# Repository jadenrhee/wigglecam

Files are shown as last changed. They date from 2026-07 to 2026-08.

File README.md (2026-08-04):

# WiggleCam

A four-lens camera where all four lenses fire at the same moment. The
four views are combined into a looping GIF that reads as 3-D, the same
effect as the Nishika N8000 film camera. A touchscreen handles the
preview and filter selection, and every shot ends with a QR code that
opens the GIF on any phone over the camera's own hotspot.

Design and firmware are done. Parts aren't ordered yet, so the images
here are renders.

<p align="center">
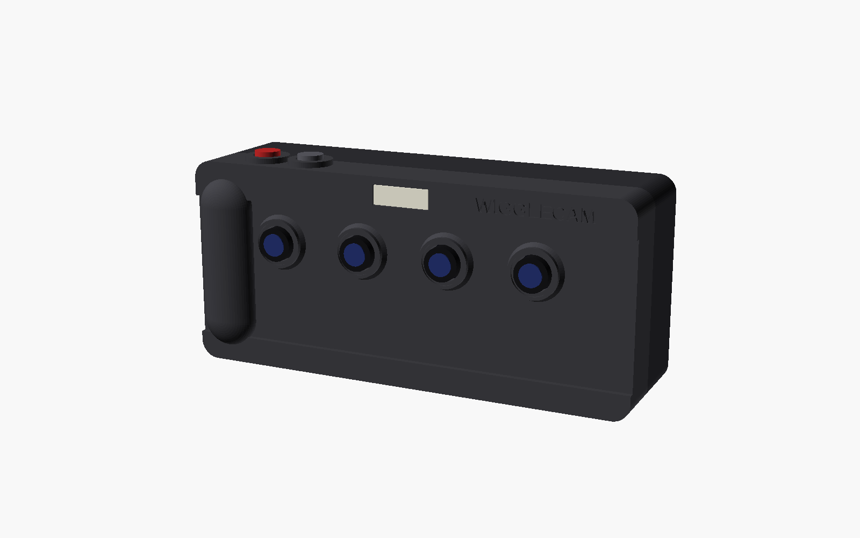
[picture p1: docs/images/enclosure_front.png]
Enclosure, front: four bezeled lenses, grip, top-plate shutter and filter buttons
  
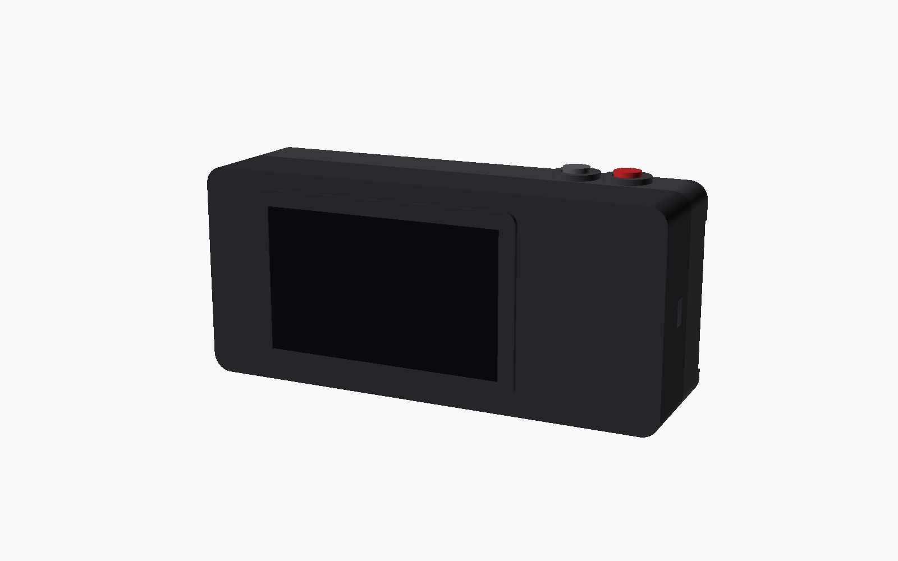
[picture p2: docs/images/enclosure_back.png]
Enclosure, back: 4.3 inch touchscreen
  
</p>

## How it works

Four 16 MP camera modules sit 40 mm apart behind the front plate. An
Arducam Camarray HAT drives all four from one clock and merges them into
a single 2x2 frame over one CSI cable. Sharing a frame puts each view at
roughly 4 MP, which is the tradeoff for hardware sync.

That shared clock is the reason for the HAT. Cameras triggered in
software drift by milliseconds, so a moving subject lands in a different
position in each frame and jumps between them instead of shifting
smoothly.

The firmware splits the frame and aligns the four views on the subject
using phase correlation on a center crop. It then applies the selected
filter and writes a bounce-looped GIF.

System wiring diagram

## Controller board

Linux is not a real-time OS, so the Pi can't be relied on to hit an
exact moment, and the jitter shows up as a flash firing outside the
exposure.
[wigglecam-controller](https://github.com/jadenrhee/wigglecam-controller)
handles the timing-critical work.

An RP2040 drives the flash at constant current and pulses the Pi the
instant the LEDs reach full current. It also debounces the shutter,
decodes the EC11 encoder, and monitors battery voltage and current
through an INA219. The Pi drives it over I2C at 0x17. The capture pulse
and an event flag come back on separate GPIO lines.

76 x 50 mm, 4 layers, DRC clean against JLCPCB's published 4-layer
rules, plus 24 checks measured off the finished layout. Not fabricated
yet either.

<p align="center">
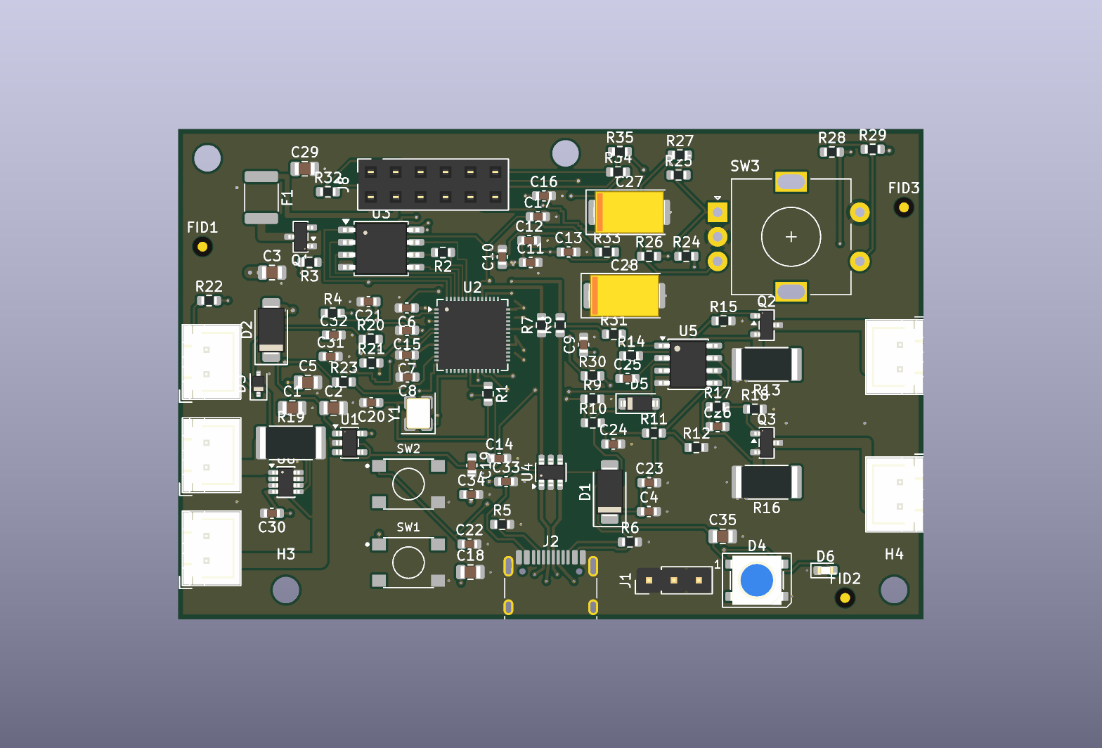
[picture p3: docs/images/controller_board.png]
Controller board, rendered top view
  
  PCB routing: front copper red, back copper blue
</p>

## Repo layout

| Path | Contents |
|---|---|
| [hardware/BOM.md](hardware/BOM.md) | full parts list, about $550 |
| [hardware/wiring.md](hardware/wiring.md) | connections, GPIO map, assembly order |
| [hardware/power-budget.md](hardware/power-budget.md) | load table and the math behind the 4.5 hour runtime |
| [hardware/safety-checklist.md](hardware/safety-checklist.md) | lithium and thermal rules. The cells are unprotected by design, so the BMS and these checks carry the safety case |
| [firmware/](firmware/) | Python app: capture, filters, alignment, GIF export, share server, UI |
| [enclosure/](enclosure/) | parametric OpenSCAD body and printing guide |
| [docs/architecture.md](docs/architecture.md) | reasoning behind each design decision |

## Running it (on the Pi)

```bash
sudo apt install -y python3-picamera2 python3-pyqt5 python3-opencv
python3 -m venv --system-site-packages .venv && source .venv/bin/activate
pip install -r firmware/requirements.txt
echo 'dtoverlay=imx519,cam0' | sudo tee -a /boot/firmware/config.txt && sudo reboot
# after reboot:
nmcli device wifi hotspot ssid WiggleCam password <choose-one>
cd firmware && python3 -m wigglecam.app
```

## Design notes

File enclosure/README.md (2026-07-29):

# Enclosure

The body is parametric OpenSCAD, all in
[wigglecam_body.scad](wigglecam_body.scad). It's styled like a wide
compact camera: raised top and bottom plates, bezeled lens rings, a
hand grip on the photographer's right, a shutter button on the top
plate, a flash window, and a raised screen bezel on the back.

Opened in [OpenSCAD](https://openscad.org) (free), pressing F5 renders the
default `PART = "assembly"`: the closed camera standing upright, with dummy
lenses/screen/button for a quick layout sanity-check. Setting `PART` to
`"front"` or `"back"` and pressing F6 renders a shell for export via
**File → Export → STL**.

The `scr_*`, `cam_*`, and `pi_*` variables hold the dimensions of the
actual delivered screen, camera modules, and Pi/UPS stack, measured with
calipers before any print. Vendor drawings drift between hardware
revisions, and a 1 mm error in the screen cutout ruins a 10-hour print.

## Printing without owning a printer

- **Public library or school makerspace.** Many offer free or at-cost
  prints. The 205 × 92 mm body fits a 220 × 220 mm bed straight-on. No
  rotation squeezes it onto a 200 × 200 mm bed (unrotated 205 mm is
  already the tightest bounding box), so for smaller beds reduce
  `body_w` or use a service with a larger bed.
- **[Craftcloud](https://craftcloud3d.com)** is a comparison marketplace
  for print services; upload the STL and pick PETG.
- **[JLC3DP](https://jlc3dp.com)** and **PCBWay** are cheap, good quality,
  and ship in about a week.

Recommended settings: **PETG** (more heat-tolerant than PLA, and the Pi 5
runs warm), 0.2 mm layers, 4 perimeters, 25 % infill.

**Orientation:** print both shells open-side down (cosmetic face up)
with supports on. The raised lens bezels, grip, and plates mean the
shells don't sit flat face-down anymore, and this way the support
marks end up inside the shell where nobody sees them.

## Assembly hardware

- 6x M3 heat-set brass inserts + M3x10 screws (join the shells)
- 16x M2x6 self-tapping screws (camera modules)
- 4x M2.5x16 standoff screws (Pi 5 + X1202 stack)
- 4x M3x8 screws (screen)
- 1x 1/4-20 hex nut, epoxied into the bottom pocket (tripod mount)
- a scrap of white PETG or frosted acrylic behind the flash window as
  a diffuser

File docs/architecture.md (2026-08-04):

# Architecture

I started from what a wigglegram actually needs and let each
requirement pick the hardware. This doc walks through that reasoning,
then covers the electronics, the data flow, and what I'd still like to
fix.

**1. Four views of the same instant.** If the four exposures are even a
few ms apart, anything moving (people, hair, leaves) ghosts between
frames and the 3-D illusion collapses. Software-triggering four
independent cameras (e.g. four ESP32-CAMs or four Pi cams on a mux that
*switches* between them) cannot achieve this. The Arducam Camarray HAT
clocks all four IMX519 sensors from one source and merges them into a
single 2×2-stitched frame. Because the sensors share that clock, the
exposures are simultaneous, and the Pi sees just one ordinary camera on
one CSI port.

**2. Parallax baseline.** The 3-D effect comes from the lenses being
horizontally offset. The enclosure spaces the four modules 40 mm apart
(120 mm outer baseline), close to the Nishika N8000 film camera that
inspired it. Frames are auto-aligned on the subject in software
(`wiggle.py`, phase correlation on a center crop) so the subject holds
still and the background does the wiggling.

**3. Handheld power.** The Pi 5 demands 5 V/5 A, beyond what generic power
banks and boost boards provide. The Geekworm X1202 (4×18650, BMS, 5.1 V/5 A) is
purpose-built for it and mounts under the Pi, keeping the top-side
camera/display connectors free.

**4. Instant sharing.** AirDrop is Apple-proprietary (AWDL) and not
implementable on a Pi. Instead the camera runs its own Wi-Fi hotspot
and a small Flask gallery (`share.py`); after each shot the touchscreen
shows a QR code that opens the GIF in any phone browser, iPhone or
Android, with no app to install.

## Data flow

```
4x IMX519 ─(hw sync)─▶ Camarray HAT ─CSI─▶ Picamera2
                                            ├── lores stream ─▶ Qt live preview (touch UI)
                                            └── still capture (4656x3496, flash bracketed)
                                                  └▶ split 2x2 ─▶ filter ─▶ align ─▶
                                                      ├▶ 4x JPEG stills
                                                      └▶ bounce GIF ─▶ Flask gallery ─▶ QR ─▶ phone
```

## Firmware layout

| Module | What it does |
|---|---|
| `config.py` | every tunable in one place |
| `camera.py` | Picamera2 setup, stitched capture, 2x2 split |
| `flash.py` | flash pulse control (v1 GPIO gate today; v2 I2C client planned) |
| `filters.py` | the filter looks (B&W, sepia, vivid, film), all pure functions |
| `wiggle.py` | subject alignment, bounce sequencing, GIF/JPEG export |
| `share.py` | hotspot gallery server + QR generation |
| `app.py` | Qt touch UI, buttons, capture orchestration |

## Known limitations / future work

- Quad synchronized mode caps each view at 2328×1748 (~4 MP). That's the
  price of single-cable hardware sync. It's enough for GIFs.
- GIF export ~2-4 s on the Pi 5; an MP4 export path would be smaller
  files and faster.
- Autofocus is per-kit (one focus setting for all four in sync mode);
  fixed-focus at ~1.5 m works well for the classic wigglegram portrait.

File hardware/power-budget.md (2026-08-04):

# Power budget

Supply: Geekworm X1202, 5.1 V, 5 A max continuous (25.5 W).

## Load table

| Load | Typical | Worst case | Duration |
|---|---|---|---|
| Pi 5 (4 cores busy, Wi-Fi AP on) | 1.2 A | 2.4 A | continuous |
| Active cooler | 0.1 A | 0.15 A | continuous |
| Camarray HAT + 4x IMX519 | 0.3 A | 0.4 A | continuous |
| 4.3" DSI display | 0.25 A | 0.3 A | continuous |
| Flash (2x XP-G3 @ 1 A) | 0 | 2.0 A | 150 ms max pulse |
| **Total continuous** | **1.85 A (9.4 W)** | **3.25 A (16.6 W)** | |
| **Total during flash pulse** | | **5.25 A** | 150 ms max |

## The flash transient

Worst-case draw during the pulse exceeds the X1202's 5 A continuous
rating by ~0.25 A for ≤150 ms. The v1 perfboard flash branch has
**2× 2200 µF** of local reservoir capacitance (the v2 controller board
carries 2× 470 µF polymer, where the same conclusion holds even more
strongly), but honest math says the caps cannot bridge that excess. It
amounts to 0.25 A × 0.15 s = 37.5 mC, while 4400 µF supplies only
4.4 mC per volt of allowed sag, about 12% of what's needed, or ~18 ms
of the 150 ms pulse. Bridging the full pulse at 1 V of sag would take
~37,500 µF. So the reservoir's real job is smaller. It feeds the LED
turn-on edge and keeps the pulse's fast di/dt off the wiring. For the
body of a worst-case pulse the X1202 itself runs ~5% over its "max
continuous" rating for under 150 ms. That is a brief overload I'm
leaning on supply headroom for, with a momentary rail droop possible,
not something the caps absorb. Two things bound the risk:

1. Firmware hard-caps the pulse at 150 ms (`flash.py`, enforced with a
   watchdog even if the capture call hangs), and the worst case is
   synthetic: the Pi's measured draw during a capture is ~1.5 A, not
   2.4 A, which puts the realistic pulse total near 4.35 A, inside
   the rating with margin.
2. If `vcgencmd get_throttled` ever reads ≠ 0x0 after flash shots,
   dropping the branch resistors to 2.7 Ω (≈0.8 A/LED) resolves it, still
   plenty of light at wigglegram distances.

## Runtime estimate

4x Samsung 35E: 4 x 3500 mAh x 3.6 V = about **50 Wh**.
At the 9.4 W typical draw and ~85% boost-converter efficiency:

50 Wh x 0.85 / 9.4 W = about **4.5 hours** of continuous shooting per
charge.

## Charging

Charging is only through the X1202's USB-C input (5 V/5 A) or its DC jack
(6-18 V), which feed the onboard charger/BMS. The cells are never charged
outside the device except with a dedicated 18650 charger.

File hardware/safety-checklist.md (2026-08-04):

# Safety checklist

This design deliberately avoids the two genuinely dangerous options for a
DIY camera: **no xenon flash** (needs a ~300 V charge circuit, a real
shock/burn hazard on perfboard) and **no raw/unmanaged LiPo packs** (the
X1202's BMS handles over-current, over-voltage, over-discharge, and
reverse-cell protection in hardware). What's left is low-voltage
(≤5.1 V) work, but lithium cells still need care.

## Batteries (the one serious hazard left in this build)

- 18650s are sourced only from a reputable specialist dealer; counterfeit
  cells are the #1 fire risk in DIY builds.
- The cells are **flat-top, unprotected, ≥8 A** types (Samsung 35E /
  Molicel M35A class). The X1202 bay is 65.3 mm, so protected cells don't
  fit, and the board's BMS provides the protection instead.
- Polarity is verified against the bay markings before every insertion.
- All four cells are matched: same brand, model, and age, and within
  0.05 V of each other before first use (measured with a multimeter).
- Charging is never left unattended and always runs on a non-flammable
  surface.
- Cells with dents, torn wrap, or heat discoloration are retired at a
  battery recycling point, never household trash.
- Cells come out before any soldering near the device.

## Electrical

- The flash board is bench-tested standalone (current per branch ≈ 1 A,
  LEDs off with the gate floating) before it connects to the Pi.
- Pi, X1202, and flash board share a common ground, confirmed with a
  continuity check before power-up.
- No conductors are left exposed after assembly; every splice is
  heat-shrunk.
- A polyfuse sits in the flash 5 V feed to protect the wiring on a short.
- Buttons switch to GND only; 5 V is never wired to a GPIO (Pi GPIOs are
  3.3 V-only and not 5 V tolerant).
- The first battery boot is outside the enclosure with a meter on the 5 V
  rail; `vcgencmd get_throttled` must read `0x0`.

## Thermal

- An active cooler is fitted to the Pi 5, and the case vent slots stay clear.
- After 15 min of live preview in the closed case, `vcgencmd measure_temp`
  stays under 75 °C; if not, the vents get enlarged.
- LED flash duty is firmware-capped at 150 ms per shot, so the LED stars
  need no heatsink at that duty cycle.

## Mechanical

- Camera and display ribbons are folded gently (folded, never creased),
  with no tension when the shells close.
- Flash and button wiring have strain relief (a zip-tie anchor).
- Nothing conductive can shift and bridge the X1202 terminals; the flash
  perfboard underside is insulated with polyimide tape.

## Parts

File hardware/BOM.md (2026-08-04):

# Bill of Materials

Prices are approximate (mid-2026, USD) and drift over time.
Every part below was chosen so the whole chain is plug-compatible. All
four synchronized cameras run off one CSI port, the screen off the DSI
port, and the 5.1 V/5 A battery HAT is rated for exactly what the Pi 5
needs.

## Core electronics

| # | Part | Qty | ~Price | Why this part |
|---|---|-----|---|---|
| 1 | Raspberry Pi 5 (8 GB) | 1 | $80 | Two 22-pin MIPI ports (cameras + display), enough CPU for live preview and GIF assembly |
| 2 | [Arducam 16MP IMX519 Autofocus Synchronized Quad-Camera Kit](https://www.arducam.com/arducam-16mp-imx519-autofocus-synchronized-quad-camera-kit-for-raspberry-pi-nvidia-jetson-nano-xavier-nx.html) | 1 | $260 | Camarray HAT hardware-syncs all 4 sensors for truly simultaneous exposure, the one thing a wigglegram cannot fake in software. Quad mode outputs one 4656×3496 frame |
| 3 | [Waveshare 4.3" DSI LCD, 800×480 capacitive touch](https://www.waveshare.com/4.3inch-dsi-lcd.htm), **Rev 2.2 or newer** | 1 | $40 | DSI leaves the CSI port free; Rev ≤2.1 will NOT boot on a Pi 5 (power-detect false short) |
| 4 | Pi 5 DSI display cable (official, or Waveshare Pi5-Display-Cable-200mm) | 1 | $4 | Pi 5 uses 22-pin mini connectors, so the generic 15-pin cable does not fit |
| 5 | [Geekworm X1202 UPS HAT](https://geekworm.com/products/x1202) | 1 | $37 | 5.1 V/5 A output (the Pi 5's full requirement), onboard BMS with over-current/over-voltage/reverse-cell protection, mounts underneath so camera/display ports stay free |
| 6 | 18650 cells, flat-top unprotected, ≥8 A rated (Samsung 35E / Molicel M35A) | 4 | $28 | X1202 bay fits max 65.3 mm, so protected cells are too long; the X1202's own BMS provides protection. Sourced from a reputable dealer (18650BatteryStore, IMR), never marketplace no-names |
| 7 | microSD 64 GB, A2 class | 1 | $12 | OS + captures |
| 8 | Raspberry Pi Active Cooler | 1 | $6 | the Pi 5 throttles without it inside a closed case |
| 9 | Cree XP-G3 (or XP-G2) LED on 20 mm star board | 2 | $8 | flash LEDs, about 500 lm each at a 1 A pulse. Needed in both versions |

## Flash + controls: v1 perfboard version (see wiring.md)

| # | Part | Qty | ~Price | Notes |
|---|---|-----|---|---|
| 10 | IRLZ44N logic-level N-MOSFET, TO-220 | 1 | $2 | fully on at a 3.3 V gate; our 2 A is nothing next to its 47 A rating |
| 11 | 2.2 Ω 5 W wirewound resistor | 2 | $2 | sets ~1 A per LED; each one dissipates 2.2 W during the pulse |
| 12 | 100 Ω 1/4 W (gate series), 100 kΩ 1/4 W (gate pulldown) | 1+1 | $1 | the pulldown keeps the flash OFF while the Pi boots |
| 13 | 2200 µF 10 V low-ESR electrolytic | 2 | $4 | local reservoir; smooths the pulse's leading edge (what it can and can't do: power-budget.md) |
| 14 | Polyfuse (PTC), 3 A hold | 1 | $1 | protects the flash wiring if something shorts |
| 15 | Perfboard 50x70 mm, JST-XH connectors, 20 AWG silicone wire, heat-shrink | - | $12 | |
| 16 | 12 mm momentary pushbutton (shutter + filter) | 2 | $4 | |

## Controls, assembly, enclosure (both versions)

| # | Part | Qty | ~Price | Notes |
|---|---|-----|---|---|
| 17 | M3 heat-set inserts + M3x10, M2x6 self-tap, M2.5x16 standoffs, M3x8 | kit | $12 | see enclosure/README.md |
| 18 | 1/4-20 hex nut (tripod mount) + epoxy | 1 | $2 | |
| 19 | Panel-mount USB-C extension (charging port) | 1 | $8 | brings the X1202's USB-C input out to the case wall |
| 20 | Enclosure print, PETG (print service) | 2 shells | $30 | see enclosure/README.md for services |

Total: about **$550 for a v1 build**. The line items sum to $553
($475 core + $26 flash/controls + $52 assembly/enclosure). A v2 build
drops the perfboard flash section (items 10-15 plus one of item 16's
two buttons; the top-plate shutter stays, −$24) and uses the
[controller board](https://github.com/jadenrhee/wigglecam-controller)
instead: $529 from this list, plus the controller's PCB fab and parts,
priced per-part in its
[partlist](https://github.com/jadenrhee/wigglecam-controller/blob/main/hardware/partlist.md).

## Compatibility cross-check (why these work together)

- Camera kit → Pi 5 **CAM0** port (needs the 22-pin cable included/adapter);
  enabled with `dtoverlay=imx519,cam0`. Uses ONE CSI port for all 4 cams.
- Display → Pi 5 **DISP1** port via Pi-5-specific cable. No conflict with cameras.
- X1202 powers the Pi through the GPIO 5 V pins at 5.1 V/5 A, the same
  budget as the official 27 W adapter, so no undervoltage warnings.
- X1202 mounts on the **bottom**; Camarray HAT sits on top of the 40-pin
  header via stacking header, and it only uses I2C + 3V3/5V/GND pins, leaving
  GPIO 17/18/27 free for our button, flash, and mode pins.
- Flash draws from the X1202 5 V rail: worst-case system peak
  (Pi 2.4 A + cooler 0.15 A + cameras 0.4 A + display 0.3 A + flash 2 A
  = 5.25 A) runs ~5% over the 5 A rating for the ≤150 ms pulse. The
  local reservoir (4400 µF on v1; 940 µF on the v2 controller) only
  smooths the leading edge; the brief overload itself rides on the
  X1202's headroom. Math in power-budget.md.

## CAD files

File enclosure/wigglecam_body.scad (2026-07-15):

// ============================================================================
// WiggleCam enclosure: parametric two-shell camera body
//
// Styled like a classic wide compact camera:
//   * raised top/bottom plates with a recessed "leatherette" mid band
//   * 4 lens holes in a horizontal row, each with a raised bezel ring
//   * flash window embedded in the top plate, engraved WIGGLECAM branding
//   * hand-grip bulge on the photographer's right, shutter button on top
// Back shell: raised screen bezel + cutout and mounting bosses for the
//   4.3" DSI touchscreen, vents, USB-C charge slot, tripod nut pocket.
// Shells join with 6x M3 screws into heat-set brass inserts.
//
// PART = "assembly" shows the closed camera standing upright (preview only).
// Set PART to "front" or "back", press F6, then File > Export STL to print.
// Every dimension is verified against the delivered parts with calipers
// before printing; vendor drawings drift between revisions.
// ============================================================================

PART    = "assembly";  // "front" | "back" | "assembly"
EXPLODE = 0;           // mm gap between shells in the assembly view

// ---- global body ----------------------------------------------------------
body_w   = 205;        // overall width  (sets the ~120 mm lens baseline)
body_h   = 92;         // overall height
body_d   = 54;         // overall depth (front+back shells)
wall     = 3;          // shell wall thickness (>=3 for rigidity)
corner_r = 8;          // outer corner radius
front_d  = 22;         // depth of front shell
back_d   = body_d - front_d;

// ---- camera-look cosmetics --------------------------------------------------
plate_h  = 16;         // top-plate band height on the front face
plate_t  = 2.5;        // how proud the top/bottom plates sit
base_h   = 12;         // bottom-plate band height
bezel_d  = 22;         // lens bezel ring outer diameter
bezel_h  = 4;          // bezel protrusion from the face
grip_w   = 26;         // grip bulge width
grip_d   = 9;          // grip protrusion from the face
grip_x   = body_w/2 - grip_w/2 - 2;
frame_t  = 2;          // screen bezel frame protrusion (back shell)

// ---- camera modules (Arducam quad kit, 25 x 25 mm boards) -----------------
cam_count      = 4;
cam_baseline   = 120;   // outermost lens centre-to-centre distance
cam_pitch      = cam_baseline / (cam_count - 1);   // 40 mm between lenses
cam_lens_d     = 16;    // clearance hole for the lens barrel
cam_board      = 25;    // module PCB is 25 x 25 mm
cam_hole_pitch = 21;    // M2 mounting holes, 21 x 21 mm pattern
cam_y          = 12;    // lens row height above body centreline

// ---- flash window (embedded in the top plate) -------------------------------
flash_w = 26;  flash_h = 9;           // diffuser window (print white PETG
flash_x = 0;   flash_y = body_h/2 - plate_h/2;   // insert or glue acrylic)

// ---- top-plate buttons (through the TOP wall) --------------------------------
// two 12 mm momentary switches: shutter (outer) + filter cycle (inner)
btn_d    = 13;                         // switch body + clearance
btn_xs   = [body_w/2 - 30, body_w/2 - 52];
btn_z    = front_d/2;                  // depth position on the top wall
collar_h = 2.5;                        // raised collar around each button

// ---- Raspberry Pi 5 + X1202 UPS stack --------------------------------------
pi_l = 85; pi_w = 56;
pi_hole_dx = 58; pi_hole_dy = 49;      // Pi mounting hole pattern
pi_boss_d = 7; pi_boss_h = 6;
stack_x = -30;                          // stack sits left of centre
stack_y = 0;

// ---- 4.3" DSI touchscreen (Waveshare), MEASURE THE ACTUAL PART --------------
scr_module_w = 122;  scr_module_h = 76;    // module outline
scr_view_w   = 106;  scr_view_h   = 63;    // visible area cutout
scr_hole_dx  = 114;  scr_hole_dy  = 68;    // M3 mounting pattern
scr_x = 18;  scr_y = 0;                    // position on back face

// ---- misc -------------------------------------------------------------------
usbc_w = 11; usbc_h = 6;               // charge-port slot to X1202 input
tripod_nut_af = 11.4;                  // 1/4-20 hex nut across-flats
screw_positions = [
    [ body_w/2-8,  body_h/2-8], [0,  body_h/2-8], [-body_w/2+8,  body_h/2-8],
    [ body_w/2-8, -body_h/2+8], [0, -body_h/2+8], [-body_w/2+8, -body_h/2+8]];
insert_d = 4.2; insert_h = 6;          // M3 heat-set insert pocket
$fn = 64;

// ============================================================================
// helpers
// ============================================================================
module body_outline() {                // rounded body cross-section, centred
    offset(corner_r) offset(-corner_r) square([body_w, body_h], center = true);
}

module rbox(w, h, d, r) {              // rounded-corner box, centred in XY
    linear_extrude(d)
        offset(r) offset(-r) square([w, h], center = true);
}

module shell(depth) {                   // one hollow half-shell
    difference() {
        rbox(body_w, body_h, depth, corner_r);
        translate([0, 0, wall])
            rbox(body_w - 2*wall, body_h - 2*wall, depth, corner_r - wall);
    }
}

// raised band across the face (top/bottom plates), exterior side is z < 0
module face_band(y0, h) {
    translate([0, 0, -plate_t])
        linear_extrude(plate_t + 0.01)
            intersection() {
                body_outline();
                translate([-body_w/2 - 1, y0]) square([body_w + 2, h]);
            }
}

module lens_positions() {
    for (i = [0 : cam_count - 1])
        translate([-cam_baseline/2 + i*cam_pitch, cam_y, 0])
            children();
}

module lens_bezels() {                  // raised ring around each lens
    lens_positions() {
        translate([0, 0, -bezel_h]) cylinder(d = bezel_d, h = bezel_h + 0.01);
        translate([0, 0, -2]) cylinder(d1 = bezel_d, d2 = bezel_d + 3, h = 2.01);
    }
}

module lens_holes() {
    lens_positions() {
        translate([0, 0, -bezel_h - 1])
            cylinder(d = cam_lens_d, h = bezel_h + wall + 2);
        // shallow step in the bezel face, reads as a lens retaining ring
        translate([0, 0, -bezel_h - 1])
            cylinder(d = cam_lens_d + 3, h = 2);
    }
}

module grip() {                         // vertical bulge, photographer's right
    intersection() {
        hull()
            for (sy = [-1, 1])
                translate([grip_x, sy*(body_h/2 - 20), 0])
                    scale([1, 1, 2*grip_d/grip_w]) sphere(d = grip_w);
        translate([-body_w/2, -body_h/2, -grip_d - 1])
            cube([body_w, body_h, grip_d + 1]);   // keep the front half only
    }
}

module cam_bosses() {                   // M2 standoffs behind each lens hole
    lens_positions()
        translate([0, 0, wall])
            for (sx = [-1, 1], sy = [-1, 1])
                translate([sx*cam_hole_pitch/2, sy*cam_hole_pitch/2, 0])
                    difference() {
                        cylinder(d = 5, h = 4);
                        translate([0, 0, 1]) cylinder(d = 1.6, h = 4);
                    }
}

module pi_bosses() {
    translate([stack_x, stack_y, wall])
        for (sx = [-1, 1], sy = [-1, 1])
            translate([sx*pi_hole_dx/2, sy*pi_hole_dy/2, 0])
                difference() {
                    cylinder(d = pi_boss_d, h = pi_boss_h);
                    translate([0, 0, 1]) cylinder(d = 2.4, h = pi_boss_h);
                }
}

module screw_bosses(depth) {
    for (p = screw_positions)
        translate([p[0], p[1], wall])
            difference() {
                cylinder(d = insert_d + 4, h = depth - wall);
                translate([0, 0, depth - wall - insert_h])
                    cylinder(d = insert_d, h = insert_h + 1);
            }
}

module vents(x0) {
    for (i = [0:5])
        translate([x0 + i*7, -body_h/2 - 1, back_d - 14])
            cube([3.5, wall + 2, 9]);
}
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

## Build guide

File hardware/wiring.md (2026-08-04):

# Wiring & Assembly

Safety notes are in [safety-checklist.md](safety-checklist.md). The build
proceeds with the batteries out until the final step.

## Two versions of the electronics

There are two versions of the flash + controls electronics in this
repo. **v2, the
[wigglecam-controller](https://github.com/jadenrhee/wigglecam-controller)
RP2040 board, is the current design.** I'm keeping v1 documented too,
because you can build it without ordering a PCB, and it's what the
Python firmware drives today.

| | v1 (perfboard) | v2 (controller board, current) |
|---|---|---|
| Flash driver | IRLZ44N MOSFET switched by Pi GPIO 18; 2.2 Ω power resistors set ~1 A per LED | op-amp constant-current sinks on the controller, settable 0-1 A per LED in 1% steps |
| Flash safety | software cap in `flash.py` | enforced in hardware on the controller: pulldown holds it off through boot, 150 ms pulse cap, 800 ms cooldown, 500 ms watchdog. Holds even if the Pi hangs |
| Shutter / mode | buttons on GPIO 17/27, debounced in software | shutter button + rotary encoder into the controller, RC + firmware debounce |
| Capture sync | software timing only | controller pulses Pi GPIO 17 once the flash is at current |
| Battery telemetry | X1202 fuel gauge (I2C 0x36) | X1202 fuel gauge, plus an in-line INA219 monitor on the controller |
| Pi connection | 3 GPIO lines + I2C | one 2x6 socket on header pins 1-12: I2C slave **0x17** (UART pins wired on the header, unused by the firmware) |
| Pi-side firmware | works today (`gpiozero`) | I2C client still to be written; register map is in the controller's [protocol doc](https://github.com/jadenrhee/wigglecam-controller/blob/main/docs/protocol.md) |

Heads up: the two versions are **mutually exclusive on the header**.
v1 *drives* GPIO 18 (flash gate) and *reads* GPIO 17 (shutter), while
v2 uses those same two pins as *inputs* from the controller (capture
sync on 17, event line on 18). Build one or the other, not both.

---

## v2: controller-board build (current)

### System block diagram

```
                 ┌─────────────┐  22-pin CSI   ┌──────────────┐
  4x IMX519 ────▶│ Camarray HAT│──────────────▶│ CAM0         │
  camera modules │ (hw sync)   │               │              │
                 └─────────────┘               │ Raspberry    │
                 ┌─────────────┐  22-pin DSI   │ Pi 5         │
  4.3" touch ◀──▶│ Rev2.2 LCD  │◀─────────────▶│ DISP1        │
                 └─────────────┘               │              │
  ┌────────────┐    5 V pack feed              │              │
  │ X1202 UPS  │═══▶ VBAT_IN ─10 mΩ─ VBAT_OUT ═▶ 5 V pins     │
  │ 4x 18650   │    (in-line INA219 telemetry) │              │
  └────────────┘                               │ GPIO 1-12    │
      ▲ USB-C (panel-mount) - charge input     └──────┬───────┘
                                                      │ 2x6 socket:
                                                      │ 5 V + GND down,
                                                      │ I2C 0x17,
                                                      │ sync -> GPIO17, ATTN -> GPIO18
  top-plate ─── SHUTTER JST ──▶ ┌─────────────────────┴────────────────┐
  shutter button                │      RP2040 camera controller        │
                                │  EC11 encoder + status LED on board  │
                                │    op-amp constant-current sinks     │
                                └───────┬─────────────────┬────────────┘
                                   LED1 │ JST        LED2 │ JST
                                        ▼                 ▼
                                     XP-G3             XP-G3
                                    (1 A pulse)       (1 A pulse)
```

### The 2x6 header (Pi GPIO pins 1-12)

The controller has a 2x6 socket that seats directly on the first
twelve pins of the Pi 5 header. The Camarray HAT stacks above it on a
tall stacking header, so these pins stay reachable.

| Pi pin (physical) | Signal | Notes |
|---|---|---|
| 1 | 3V3 | reference only, the controller doesn't use it |
| 2, 4 | 5 V | controller power in, through a 3 A polyfuse and a reverse-polarity FET; this node is also the flash rail |
| 3, 5 | SDA, SCL (GPIO 2/3) | controller is I2C slave **0x17** at 400 kHz; the Pi 5's onboard 1.8 kΩ pullups serve the bus |
| 6, 9 | GND | common ground |
| 7 | GPIO 4 | spare, unused |
| 8 | GPIO 14 (TXD) | Pi TX to controller RX, wired but unused by the current firmware (330 Ω in series) |
| 10 | GPIO 15 (RXD) | controller TX to Pi RX, wired but unused by the current firmware (330 Ω in series) |
| 11 | GPIO 17 | **capture sync, into the Pi.** Pulses high when a trigger fires; the capture loop waits on this edge |
| 12 | GPIO 18 | **ATTN, into the Pi.** High while a button/encoder event is waiting; the Pi can poll it or take an interrupt |

Three devices share the Pi's one I2C bus at different addresses, so
nothing collides: Camarray HAT control, X1202 fuel gauge (0x36), and
the controller (0x17).

### Off-board connections

Signal-level runs use JST-XH. The pack feed does **not**. An XH contact
is rated 3 A and this path carries the full system current, 3.25 A
worst-case continuous and 5.25 A during a flash pulse (power-budget.md),
so VBAT_IN/VBAT_OUT get XT30 connectors (or a screw-terminal block if
you'd rather not crimp). Note the current controller board rev lands
this path on JST-XH footprints (J5/J6). Leave those unpopulated and
solder the XT30 pigtails straight into the J5/J6 through-holes.

| Connector | Type | Goes to | Notes |
|---|---|---|---|
| LED1, LED2 | JST-XH | one Cree XP-G3 star each | constant-current sinks, so **no ballast resistors**. Current is set per shot over I2C (`FLASH_PCT`) |
| SHUTTER | JST-XH | top-plate shutter button | has a TVS (surge protector) diode at the connector, since this line leaves the enclosure |
| VBAT_IN | XT30 | X1202 5 V output | pack feed in |
| VBAT_OUT | XT30 | Pi 5 V pins | pack feed out, through the 10 mΩ shunt the INA219 reads for real system voltage and current |

The filter/mode selector is the rotary encoder **on the controller
board itself** (the knob pokes through the enclosure wall). v1's
second pushbutton goes away.

### Bring-up

Follow the controller repo's
[README](https://github.com/jadenrhee/wigglecam-controller#next-steps-in-order).
Short version: power the board from USB-C first (the flash rail is
intentionally dead on USB power), flash `camctrl.uf2` over BOOTSEL,
check that `i2cdetect -y 1` on the Pi shows 0x17, and bench-test the
flash sinks at 1 A per branch with a current probe **before** the LEDs
get connected. On this board revision, don't press BOOTSEL while it's
running.

**Firmware status:** `firmware/wigglecam` currently drives the v1
electronics directly (`gpiozero`). The v2 I2C client (trigger, flash
setup, encoder/button events, battery readings) still needs to be
written. The full register map is in the controller repo's
[protocol doc](https://github.com/jadenrhee/wigglecam-controller/blob/main/docs/protocol.md).

---

## v1: direct-GPIO perfboard build

In the original electronics everything hangs straight off the Pi
header. No PCB order needed, and the current Python firmware supports
it as-is.

### System block diagram

```
                 ┌─────────────┐  22-pin CSI   ┌──────────────┐
  4x IMX519 ────▶│ Camarray HAT│──────────────▶│ CAM0         │
  camera modules │ (hw sync)   │               │              │
                 └─────────────┘               │ Raspberry    │
                 ┌─────────────┐  22-pin DSI   │ Pi 5         │
  4.3" touch ◀──▶│ Rev2.2 LCD  │◀─────────────▶│ DISP1        │
                 └─────────────┘               │              │
                                               │ GPIO17 ◀── shutter button ── GND
  ┌────────────┐  5.1V/5A via GPIO 5V pins     │ GPIO27 ◀── mode button ──── GND
  │ X1202 UPS  │──────────────────────────────▶│ GPIO18 ───▶ flash gate
  │ 4x 18650   │────── 5V flash tap ──▶ flash board ──▶ 2x XP-G3 LED
  └────────────┘                               └──────────────┘
      ▲ USB-C (panel-mount, case wall): charge input
```

### GPIO map

| Pin (BCM) | Direction | Function | Notes |
|---|---|---|---|
| GPIO 17 | in, pull-up | Shutter button | Button shorts to GND; debounced in software |
| GPIO 18 | out | Flash MOSFET gate | Boot-default pull-down = flash stays off during boot |
| GPIO 27 | in, pull-up | Filter/mode button | Optional |
| I2C (GPIO 2/3) | bidir | Camarray HAT control + X1202 fuel gauge (0x36) | Shared bus, different addresses, no conflict |

### Flash driver schematic

```
   X1202 5V tap ──── PTC 3A ────┬──────────────┬──────────────┐
                                │              │              │
                              ═╪═ 2200µF     ═╪═ 2200µF       │
                                │  10V         │  10V         ├─────────────┐
                               GND            GND             │             │
                                                            [2.2Ω 5W]    [2.2Ω 5W]
                                                              │             │
                                                            ▼ XP-G3      ▼ XP-G3
                                                              │             │
                                                              └──────┬──────┘
                                                                     │ D
  Pi GPIO18 ────[100Ω]────┬──────────────────────────────────────── G   IRLZ44N
                          │                                          │ S
                       [100kΩ]                                       │
                          │                                          │
                         GND ────────────────────────────────────── GND (common with Pi)
```

Branch current check: (5.1 V − ~2.9 V LED Vf) / 2.2 Ω ≈ **1.0 A per LED**,
2.0 A total. Resistor dissipation I²R ≈ 2.2 W each, only during the
≤150 ms pulse (firmware-capped in `flash.py`), so 5 W parts loaf.
MOSFET dissipation at 2 A with Rds(on) ≈ 0.04 Ω at 3.3 V gate ≈ 0.16 W, no
heatsink needed. The 100 kΩ pulldown guarantees the gate is low (flash off)
whenever the Pi is booting or the firmware isn't running.

**Grounds must be common:** flash board GND, X1202 GND, and Pi GND are the
same net, starred at the X1202 output terminal.

---

## Assembly order (both versions)

The build comes up incrementally, each stage verified before the next is added:

1. **Bare Pi bench-test** (official 27 W adapter, no HATs): Raspberry Pi OS
   Bookworm 64-bit flashed, booted, updated.
2. **Cameras:** the Camarray HAT connects to CAM0 with the 22-pin cable
   (contacts on the correct side per Arducam's Pi 5 guide) and the 4
   modules mount to it. `dtoverlay=imx519,cam0` goes in
   `/boot/firmware/config.txt`, then a reboot and a check with
   `libcamera-still --list-cameras` and a test capture.
3. **Display:** connects to DISP1 with the Pi-5-specific cable, driver-free
   on Bookworm, touch verified.
4. **Flash board:** soldered per the schematic on perfboard and bench-tested
   alone before it connects to the Pi: powered from a bench/USB 5 V source, the
   gate driven from 3.3 V through a resistor, ~1 A per branch confirmed with
   a multimeter in series, and the LEDs confirmed OFF with the gate floating
   (pulldown working).
5. **Buttons:** each wires between its GPIO and GND, no external resistors
   (internal pull-ups).
6. **X1202:** mounts under the Pi on its standoffs, 5 V feed set per the
   [X1202 wiki](https://wiki.geekworm.com/X1202). Each 18650's orientation
   is checked twice against the bay markings before insertion; reverse
   protection exists but isn't leaned on.
7. **First integrated boot on battery,** outside the enclosure, with a
   multimeter on the 5 V rail; `vcgencmd get_throttled` must return `0x0`.
8. **Software:** `sudo apt install python3-picamera2 python3-pyqt5
   python3-opencv`, `pip install -r firmware/requirements.txt`, then
   `python3 -m wigglecam.app`. The hotspot comes up with
   `nmcli device wifi hotspot ssid WiggleCam password <chosen>`.
9. **Enclosure:** only after everything works on the bench. Heat-set inserts
   go in, the stack seats, ribbons fold (never creased sharply), flash and
   button wiring get zip-tie strain relief, then the shells close.

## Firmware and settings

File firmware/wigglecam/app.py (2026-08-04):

"""WiggleCam main application.

Touch UI on the 4.3" DSI screen: live preview of the stitched 2x2
lores stream (all four views at once), filter carousel, shutter, and
a QR overlay after each shot for downloading to a phone.

Run on the Pi:  python3 -m wigglecam.app
"""

import sys
import threading

from PyQt5 import QtCore, QtWidgets
from gpiozero import Button

from . import config
from .camera import QuadCamera
from .filters import FILTERS, FILTER_NAMES
from .flash import Flash
from .share import ShareServer
from .wiggle import save_wigglegram

try:
    from picamera2.previews.qt import QGlPicamera2
except ImportError:
    QGlPicamera2 = None


class WiggleCamWindow(QtWidgets.QMainWindow):
    shot_saved = QtCore.pyqtSignal(str)   # gif filename, emitted off-thread
    mode_pressed = QtCore.pyqtSignal()    # hardware mode button, off-thread

    def __init__(self):
        super().__init__()
        self.setWindowTitle("WiggleCam")

        self.cam = QuadCamera()
        self.flash = Flash()
        self.share = ShareServer()
        self.share.start()

        self.filter_idx = 0
        self._busy = threading.Lock()

        self._build_ui()
        self.cam.start()

        # Physical controls mirror the on-screen ones.
        self.shutter_btn = Button(config.PIN_SHUTTER, pull_up=True,
                                  bounce_time=0.05)
        self.shutter_btn.when_pressed = self.trigger_capture
        self.mode_btn = Button(config.PIN_MODE, pull_up=True,
                               bounce_time=0.05)
        # gpiozero fires callbacks on its own thread and Qt widgets are
        # GUI-thread-only, so hop through a queued signal (same pattern
        # as shot_saved) instead of calling next_filter directly.
        self.mode_btn.when_pressed = lambda: self.mode_pressed.emit()

        self.shot_saved.connect(self._show_qr)
        self.mode_pressed.connect(self.next_filter)

    # ----------------------------------------------------------------- UI --
    def _build_ui(self):
        central = QtWidgets.QWidget()
        layout = QtWidgets.QVBoxLayout(central)

        if QGlPicamera2 is not None:
            self.preview = QGlPicamera2(self.cam.picam, keep_ar=True)
        else:
            self.preview = QtWidgets.QLabel("preview unavailable")
        layout.addWidget(self.preview, stretch=1)

        bar = QtWidgets.QHBoxLayout()
        self.filter_label = QtWidgets.QPushButton(FILTER_NAMES[0])
        self.filter_label.setMinimumHeight(56)
        self.filter_label.clicked.connect(self.next_filter)
        bar.addWidget(self.filter_label)

        shoot = QtWidgets.QPushButton("●")
        shoot.setMinimumHeight(56)
        shoot.setStyleSheet("font-size:28px;color:red")
        shoot.clicked.connect(self.trigger_capture)
        bar.addWidget(shoot, stretch=1)
        layout.addLayout(bar)

        self.setCentralWidget(central)

    def next_filter(self):
        self.filter_idx = (self.filter_idx + 1) % len(FILTER_NAMES)
        self.filter_label.setText(FILTER_NAMES[self.filter_idx])

    # ------------------------------------------------------------ capture --
    def trigger_capture(self):
        if not self._busy.acquire(blocking=False):
            return  # capture already in flight
        threading.Thread(target=self._capture_worker, daemon=True).start()

    def _capture_worker(self):
        try:
            stitched = self.flash.fire_around(self.cam.capture_stitched)
            views = self.cam.split(stitched)
            f = FILTERS[FILTER_NAMES[self.filter_idx]]
            views = [f(v) for v in views]
            gif_path = save_wigglegram(views)
            self.shot_saved.emit(gif_path.name)
        finally:
            self._busy.release()

    def _show_qr(self, gif_name: str):
        qr = self.share.qr_image(gif_name)
        dlg = QtWidgets.QDialog(self)
        dlg.setWindowTitle("Scan to download")
        lay = QtWidgets.QVBoxLayout(dlg)
        label = QtWidgets.QLabel()
        qr.save("/dev/shm/wiggle_qr.png")   # tmpfs, no SD-card wear
        label.setPixmap(_load("/dev/shm/wiggle_qr.png"))
        label.setAlignment(QtCore.Qt.AlignCenter)
        lay.addWidget(label)
        lay.addWidget(QtWidgets.QLabel(self.share.url(gif_name)))
        QtCore.QTimer.singleShot(15000, dlg.accept)  # auto-dismiss
        dlg.exec_()

    def closeEvent(self, event):
        self.cam.stop()
        self.flash.close()
        event.accept()


def _load(path):
    from PyQt5.QtGui import QPixmap
    return QPixmap(path)


def main():
    app = QtWidgets.QApplication(sys.argv)
    win = WiggleCamWindow()
    win.showFullScreen()
    sys.exit(app.exec_())


if __name__ == "__main__":
    main()

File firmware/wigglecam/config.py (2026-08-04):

"""Central configuration for the WiggleCam firmware."""

from pathlib import Path

# ---------------------------------------------------------------- capture ---
# The Arducam IMX519 quad Camarray HAT presents all four sensors as ONE
# camera. In quad-channel (synchronized) mode the frame is a 2x2 grid:
#   [cam TL | cam TR]
#   [cam BL | cam BR]
# Max stitched still output is 4656x3496 (each view 2328x1748).
NUM_CAMS = 4
GRID = (2, 2)                      # rows, cols of the stitched frame
STITCHED_STILL_SIZE = (4656, 3496)
# Lower-res stitched stream used for the live preview (keeps UI fluid).
STITCHED_PREVIEW_SIZE = (1280, 960)

# Reorder table applied after the 2x2 split: entry p is the stitched-frame
# quadrant index (0 TL, 1 TR, 2 BL, 3 BR) of the camera at physical
# left-to-right position p. camera.split() emits
# [views[CAM_ORDER[0]], ..., views[CAM_ORDER[3]]]. A ribbon-routing swap
# between two cameras is remapped here instead of re-cabling.
CAM_ORDER = [0, 1, 2, 3]

# ------------------------------------------------------------------- GPIO ---
PIN_SHUTTER = 17          # momentary button to GND, internal pull-up
PIN_FLASH = 18            # gate of the flash MOSFET (active high)
PIN_MODE = 27             # optional second button: cycle filters

FLASH_PULSE_S = 0.120     # nominal manual pulse length (Flash.pulse);
                          # captures use Flash.fire_around instead
FLASH_MAX_PULSE_S = 0.150 # hard safety cap enforced in flash.py

# ---------------------------------------------------------------- wiggle ----
GIF_FPS = 12.5            # playback speed of the bounce loop. GIF frame
                          # delays quantize to 10 ms steps, so use a rate
                          # whose period is a whole centisecond (80 ms
                          # here); asking for 12 fps would store 80 ms too
BOUNCE = True             # 1-2-3-4-3-2 loop instead of 1-2-3-4
ALIGN = True              # auto-align frames on the subject before export

# ---------------------------------------------------------------- storage ---
CAPTURE_DIR = Path.home() / "wigglecam_captures"
CAPTURE_DIR.mkdir(exist_ok=True)

# ---------------------------------------------------------------- sharing ---
SHARE_PORT = 8080
# NetworkManager AP-mode default address. share.py derives the actual
# local IP at runtime and only falls back to this.
HOTSPOT_IP = "10.42.0.1"

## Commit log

2026-07-02 Project scaffold: README and architecture doc for 4-lens wigglegram camera
2026-07-02 Hardware design: BOM, wiring guide, flash driver, power budget, safety checklist
    Verified parts: Arducam IMX519 synchronized quad kit (Pi 5 via
    dtoverlay=imx519,cam0), Geekworm X1202 5.1V/5A UPS, Waveshare 4.3in
    DSI LCD (must be Rev 2.2+ for Pi 5).
2026-07-02 Firmware: synchronized capture, filters, subject alignment, GIF export, QR share server, Qt touch UI
2026-07-02 Enclosure: parametric OpenSCAD two-shell body and printing guide
    [wigglecam_body.scad]
2026-07-03 Enclosure: restyle body as a camera — lens bezels, grip, top-plate buttons
    Cosmetic rework of the two-shell body so it reads as a camera instead of
    a plain box: raised lens bezel rings, top/bottom plates with recessed mid
    band, hand grip, flash window and engraved branding in the top plate, and
    a raised screen bezel on the back. Shutter button moves to the top wall
    and gains the second (filter) button the BOM always listed. Assembly view
    now shows the closed body upright with colored mockup hardware. All
    functional dimensions, mounts, and cutouts unchanged; README updated with
    print orientation (open-side down, supports inside).
    [wigglecam_body.scad]
2026-07-03 README: visual overview — enclosure renders, system diagram, controller gallery
    Enclosure front/back renders at the top, an SVG system wiring diagram
    (mirrors hardware/wiring.md), and a controller-board section with the
    top render and a copper routing view, linking to wigglecam-controller.
2026-07-04 Hardware docs: document both electronics builds, reword throughout
    wiring.md, BOM.md and architecture.md now cover the v1 perfboard
    circuit and the v2 controller board as alternative builds, with v2 as
    the current design. New system diagram for the v2 build. Wording pass
    over all the docs and code comments.
    [wigglecam_body.scad]
2026-07-05 Update BOM.md
    Removed outdated pricing and instructions for BOM. Updated total costs for v1 and v2 builds.
2026-07-15 Local 3DCAM updates
    [wigglecam_body.scad]
2026-07-18 README: tighten to a presentation overview
    Drop the status/next-step banner and the build-notes section; keep
    the page focused on what the camera is and how it works.
2026-07-18 README: cut to essentials
2026-07-29 Capture color order, flash/exposure sync, thread safety; doc math
    - Picamera2's 'RGB888' is BGR in memory: request BGR888 so the
    filter/export pipeline actually gets RGB, ending red/blue-swapped
    GIFs and stills.
    - Stills use capture_request(flush=True): the frame's exposure starts
    after the flash is lit, instead of grabbing an already-exposed
    buffer from the preview queue.
    - Hardware mode button marshals to the Qt thread via a signal instead
    of touching widgets from the gpiozero callback thread.
    - Alignment crop margin derives from the measured shifts; phase
    correlation windowed (Hanning); GIF timing stated honestly
    (12.5 fps after centisecond quantization).
    - QR URL resolves t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
    [app.py, camera.py, config.py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]
2026-07-31 Docs: I2C-only claim everywhere, buildable pack-feed note, reservoir scoping
    - README and the system diagram no longer present UART as a live
    channel (wired but unused by the controller firmware).
    - Pack-feed note now gives a buildable instruction: solder the XT30
    pigtails into the unpopulated J5/J6 through-holes (the board has no
    jumper bypass).
    - Flash-transient reservoir figures scoped per version (4400 uF v1
    perfboard, 940 uF v2 controller); conclusion unchanged.
2026-08-03 README: rewrite in plainer language, fix a few overclaims
    Rewrote the front page so it reads the way I'd actually explain the
    project. Also corrected some things the old wording got wrong or
    oversold: the board isn't fabricated, DRC clean against JLCPCB's
    published rules is my own check and not a manufacturer's, and the
    capture pulse rides a dedicated GPIO line rather than I2C.
2026-08-04 Docs: plainer wording throughout
    Rewrote the README in a plainer register and swept the rest of the
    repo for the same: replaced dashes used as punctuation, dropped the
    stock phrasings, and cut a few lines that read like product copy.
    Only comments and docstrings changed in source files. No technical
    content, numbers, or claims were altered.
    [app.py, camera.py, config.py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]
